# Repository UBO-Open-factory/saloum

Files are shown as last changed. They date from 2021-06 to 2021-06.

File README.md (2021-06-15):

# saloum
Projet Saloum pour TOCIO

1.Présentation du projet
Le projet DeltaSaloum est un projet de captation de données physico-chimiques dans le delta du Saloum afin d'analyser la variabilité de l'environnement vis-à-vis de la variabilité de l'environnement.
Les données captées  sont visualisées à distance via une application Web.
Le réseau utilisé est le réseau 2G ou 3G.

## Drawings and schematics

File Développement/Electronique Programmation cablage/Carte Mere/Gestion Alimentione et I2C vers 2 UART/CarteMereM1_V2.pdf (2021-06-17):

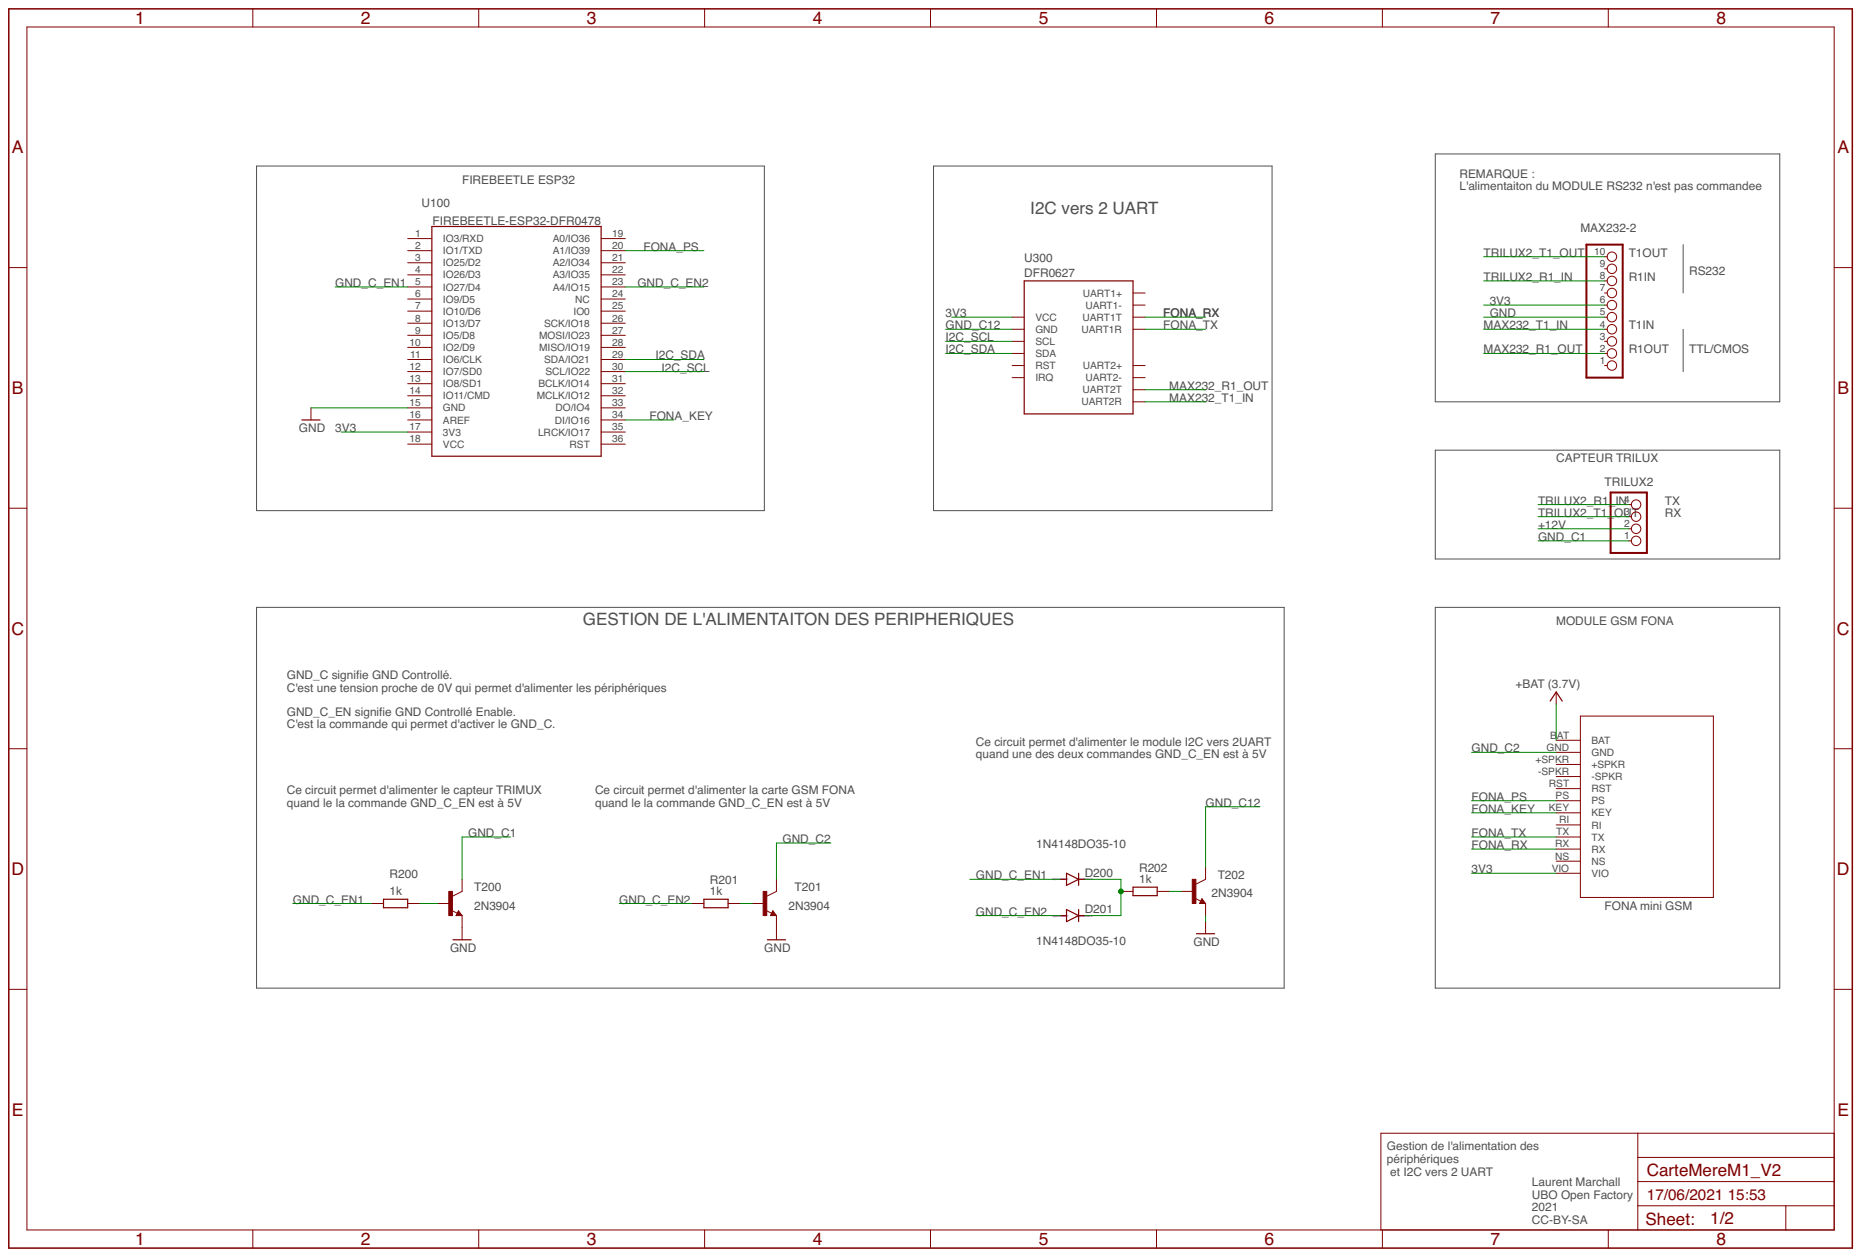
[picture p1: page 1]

REMARQUE : L'alimentaiton du MODULE RS232 n'est pas commandee

GESTION DE L'ALIMENTAITON DES PERIPHERIQUES

GND_C signifie GND Controllé. C'est une tension proche de 0V qui permet d'alimenter les périphériques GND_C_EN signifie GND Controllé Enable. C'est la commande qui permet d'activer le GND_C.

Ce circuit permet d'alimenter le module I2C vers 2UART
quand une des deux commandes GND_C_EN est à 5V

Ce circuit permet d'alimenter le capteur TRIMUX
quand le la commande GND_C_EN est à 5V

Ce circuit permet d'alimenter la carte GSM FONA

Gestion de l'alimentation des périphériques et I2C vers 2 UART Laurent Marchall UBO Open Factory 2021 CC-BY-SA

Sheet: 1/2

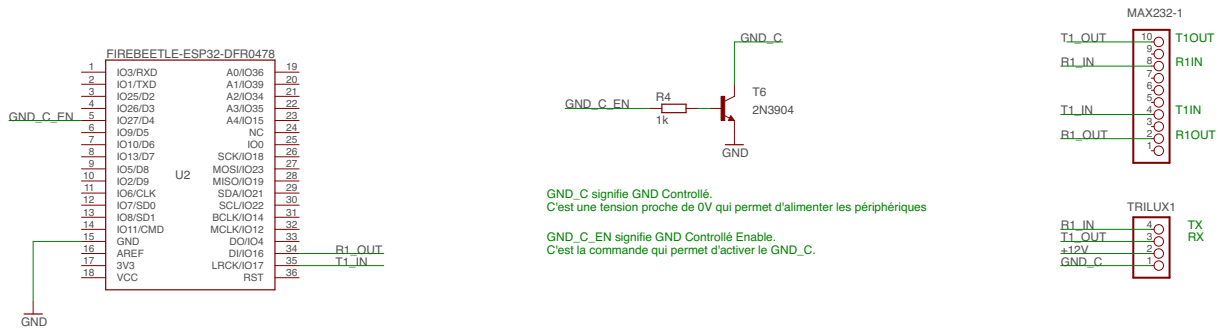
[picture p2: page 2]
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

Extrait du schéma électrique fourni par Jonathan-Flye-Sainte-Marie Laboratoire LEMAR, UBO

Sheet: 1/2

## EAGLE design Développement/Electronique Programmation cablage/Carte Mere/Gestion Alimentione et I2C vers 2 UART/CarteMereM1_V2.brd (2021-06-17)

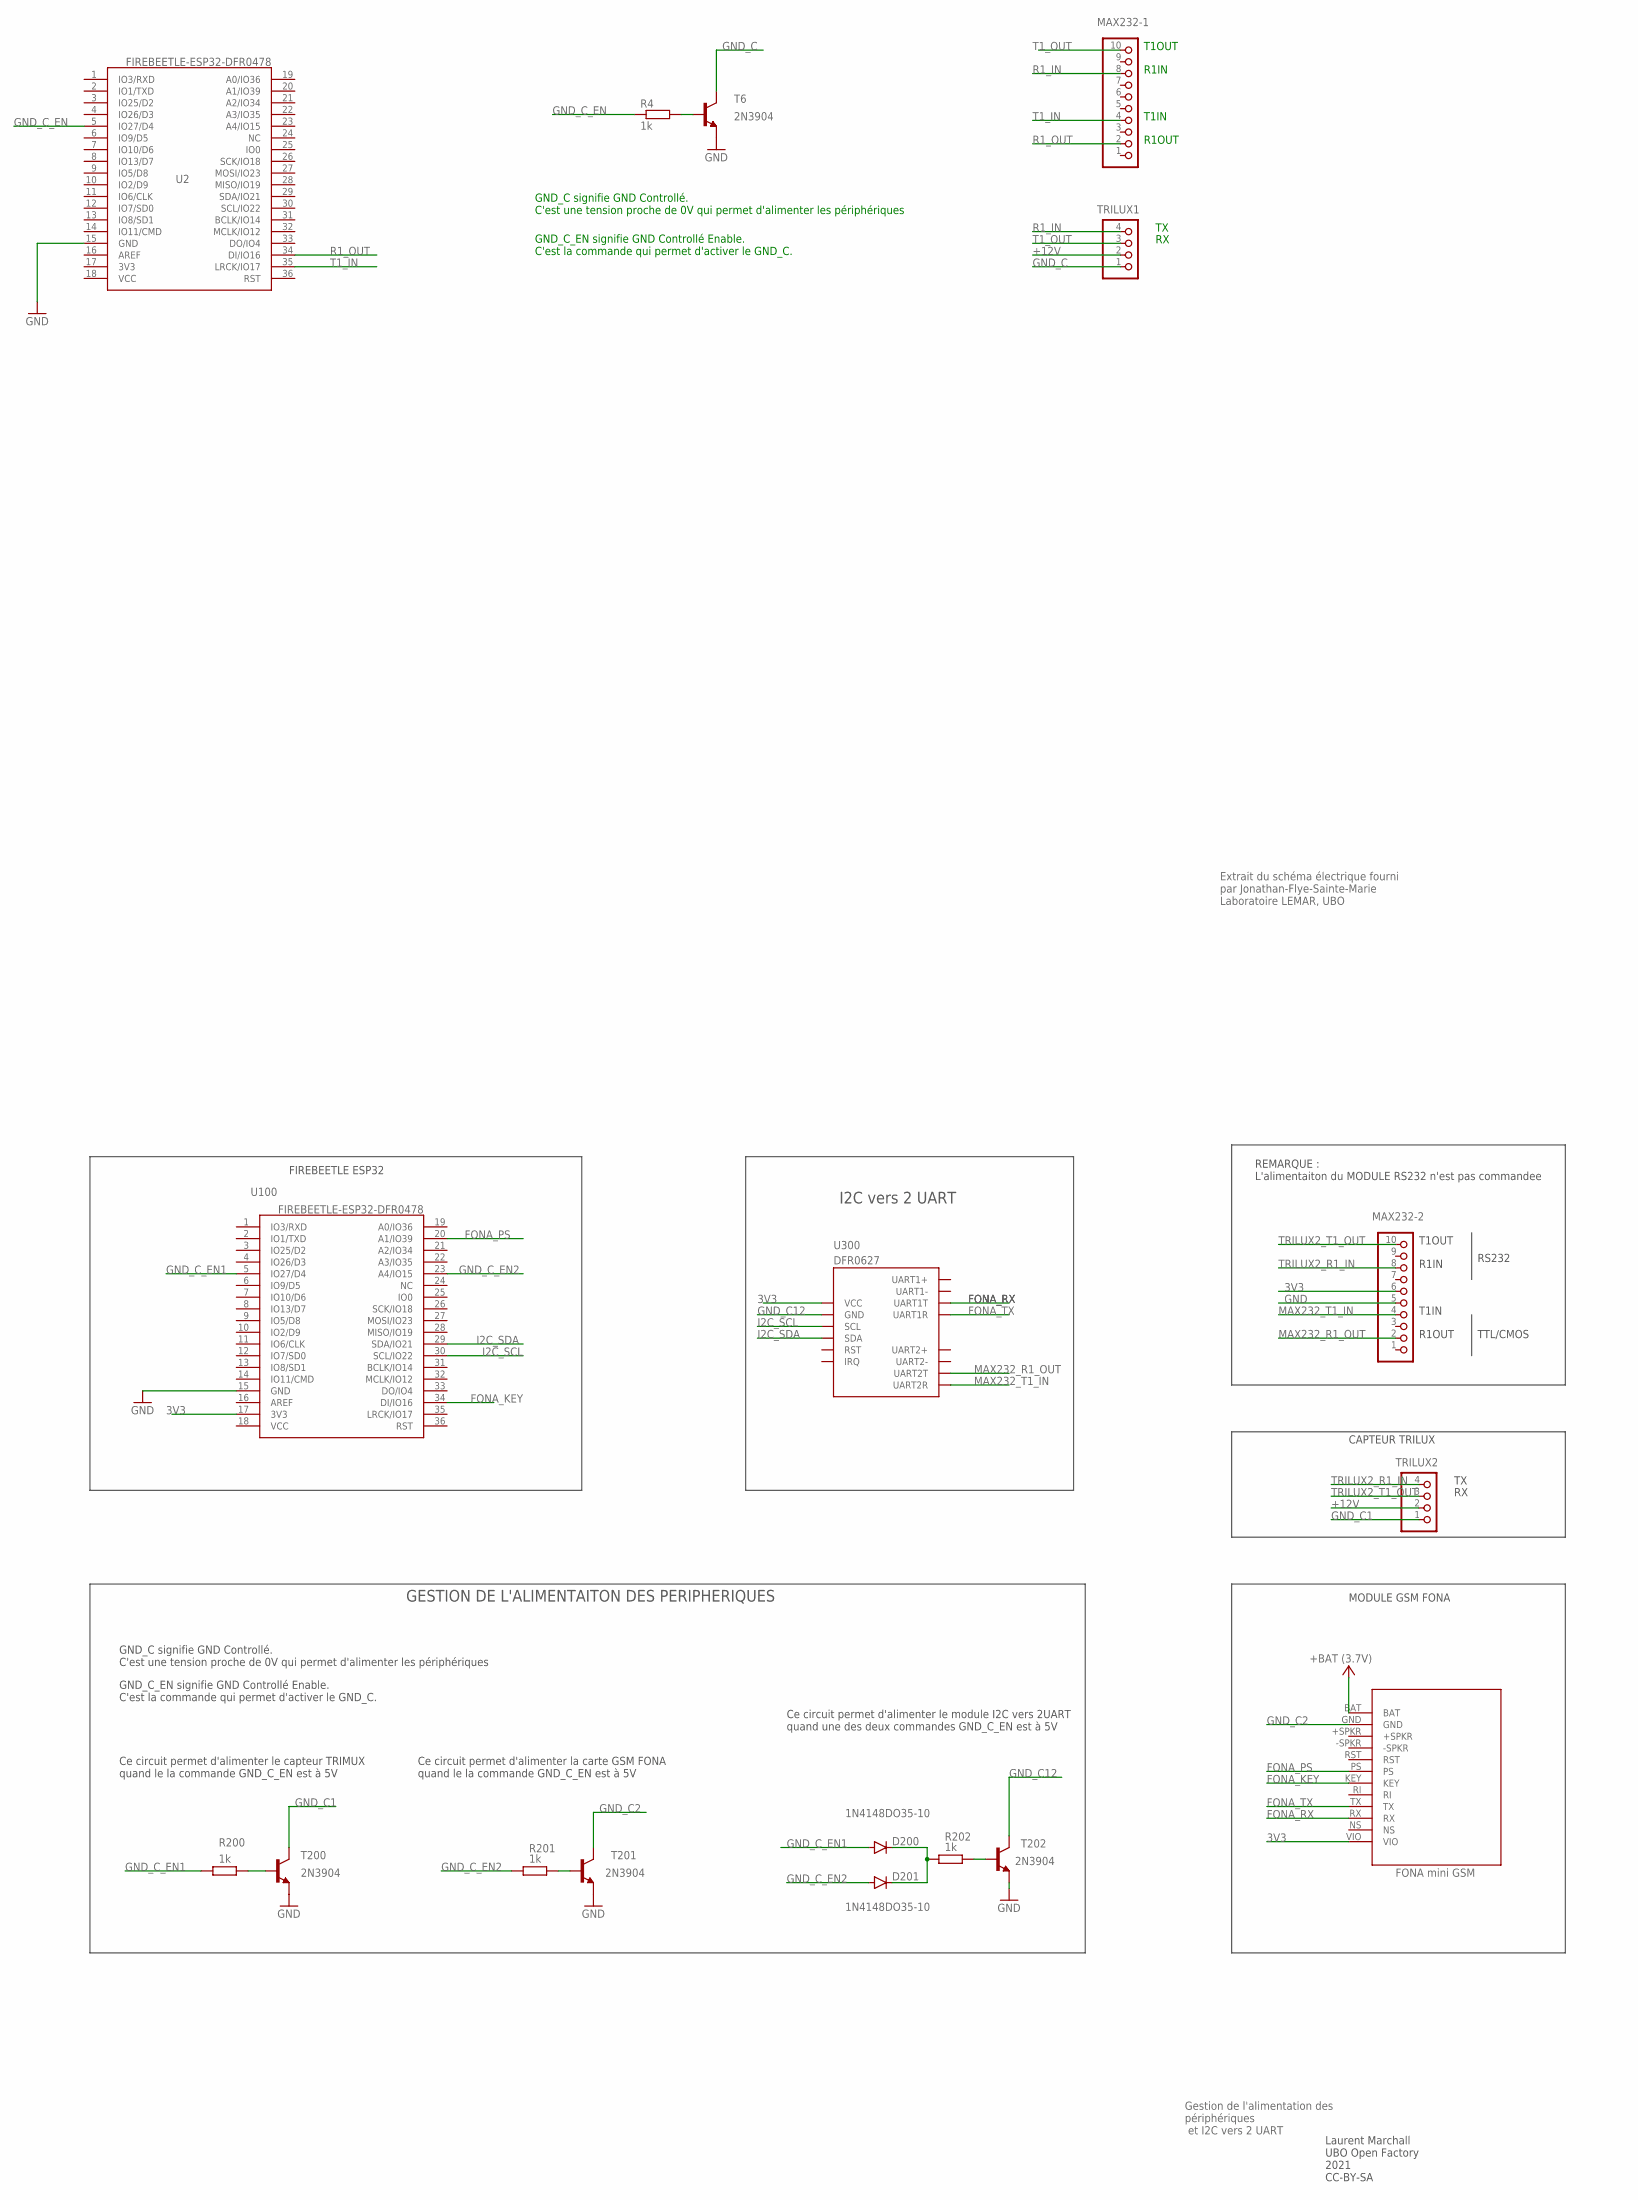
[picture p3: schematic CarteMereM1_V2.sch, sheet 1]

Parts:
D200, D201: 1N4148DO35-10; DO35-10
MAX232-1, MAX232-2: PINHD-1X10; 1X10
R4, R200, R201, R202: 1k; 0204/7
T6, T200, T201, T202: 2N3904; TO92
TRILUX1, TRILUX2: PINHD-1X4; 1X04
U2, U100: FIREBEETLE-ESP32-DFR0478; FIREBEETLE_ESP32
U300: DFR0627; DUAL-UART-MODULE-DFR0627
U$1: FONA_MINI_GSM

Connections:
3V3: MAX232-2.6, U100.17 (3V3), U300.VCC, U$1.VIO
+12V: TRILUX1.2, TRILUX2.2
FONA_KEY: U100.34 (DI/IO16), U$1.KEY
FONA_PS: U100.20 (A1/IO39), U$1.PS
FONA_RX: U300.UART1T, U$1.RX
FONA_TX: U300.UART1R, U$1.TX
GND: MAX232-2.5, T6.3 (E), T200.3 (E), T201.3 (E), T202.3 (E), U2.15 (GND), U100.15 (GND)
GND_C: T6.1 (C), TRILUX1.1
GND_C1: T200.1 (C), TRILUX2.1
GND_C2: T201.1 (C), U$1.GND
GND_C12: T202.1 (C), U300.GND
GND_C_EN: R4.1, U2.5 (IO27/D4)
GND_C_EN1: D200.A, R200.1, U100.5 (IO27/D4)
GND_C_EN2: D201.A, R201.1, U100.23 (A4/IO15)
I2C_SCL: U100.30 (SCL/IO22), U300.SCL
I2C_SDA: U100.29 (SDA/IO21), U300.SDA
MAX232_R1_OUT: MAX232-2.2, U300.UART2T
MAX232_T1_IN: MAX232-2.4, U300.UART2R
unnamed: R200.2, T200.2 (B)
unnamed: R201.2, T201.2 (B)
unnamed: R202.2, T202.2 (B)
unnamed: D200.C, D201.C, R202.1
unnamed: R4.2, T6.2 (B)
R1_IN: MAX232-1.8, TRILUX1.4
R1_OUT: MAX232-1.2, U2.34 (DI/IO16)
T1_IN: MAX232-1.4, U2.35 (LRCK/IO17)
T1_OUT: MAX232-1.10, TRILUX1.3
TRILUX2_R1_IN: MAX232-2.8, TRILUX2.4
TRILUX2_T1_OUT: MAX232-2.10, TRILUX2.3
VCC: U$1.BAT

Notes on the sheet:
Gestion de l'alimentation des périphériques et I2C vers 2 UART
R1OUT
T1IN
R1IN
T1OUT
GND_C signifie GND Controllé. C'est une tension proche de 0V qui permet d'alimenter les périphériques
GND_C_EN signifie GND Controllé Enable. C'est la commande qui permet d'activer le GND_C.
Ce circuit permet d'alimenter le capteur TRIMUX quand le la commande GND_C_EN est à 5V
Ce circuit permet d'alimenter la carte GSM FONA quand le la commande GND_C_EN est à 5V
Ce circuit permet d'alimenter le module I2C vers 2UART quand une des deux commandes GND_C_EN est à 5V
GESTION DE L'ALIMENTAITON DES PERIPHERIQUES
I2C vers 2 UART
Laurent Marchall UBO Open Factory 2021 CC-BY-SA
Extrait du schéma électrique fourni par Jonathan-Flye-Sainte-Marie Laboratoire LEMAR, UBO
RS232
TTL/CMOS
REMARQUE : L'alimentaiton du MODULE RS232 n'est pas commandee
MODULE GSM FONA
CAPTEUR TRILUX
FIREBEETLE ESP32

Board: 2 copper layers, 18 parts (0 on the bottom side), 29 nets, no tracks yet.

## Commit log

2021-06-15 version initiale
    Ajout de la présentation générale
2021-06-17 ajout Modif Carte mere
    - Gestion alimentaiton et module I2C vers 2UART
    [CarteMereM1_V2.brd, CarteMereM1_V2.sch]
